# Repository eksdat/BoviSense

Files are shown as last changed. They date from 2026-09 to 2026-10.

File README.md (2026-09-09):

# BoviSense

Sistema embarcado de monitoramento ambiental e controle adaptativo de ventilação para instalações de bovinos leiteiros.

> Projeto acadêmico e experimental desenvolvido com ESP32, sensores ambientais e controle automático de ventilação, com foco em ambiência animal, eficiência energética e possibilidade de futura aplicação em instalações pecuárias reais.

---

## Sobre o projeto

A qualidade ambiental em instalações destinadas a bovinos leiteiros depende de diferentes fatores, incluindo temperatura, umidade relativa, ventilação, concentração de gases e características construtivas do galpão.

Sistemas de ventilação mecânica são utilizados para melhorar as condições ambientais, porém o funcionamento contínuo dos ventiladores pode resultar em consumo energético desnecessário em períodos nos quais a capacidade máxima de ventilação não é necessária.

Este projeto propõe o desenvolvimento de um sistema embarcado capaz de monitorar variáveis ambientais e controlar automaticamente a ventilação de acordo com as condições observadas.

A primeira versão será desenvolvida como uma prova de conceito em escala reduzida.

---

## Problema de pesquisa

A ventilação contínua pode proporcionar condições ambientais adequadas, porém pode consumir energia mesmo quando sua capacidade máxima não é necessária.

Por outro lado, reduzir a ventilação sem considerar as condições ambientais pode prejudicar o conforto térmico dos animais e a qualidade do ar.

A pergunta central do projeto é:

> Um sistema embarcado de controle adaptativo baseado em medições ambientais locais pode reduzir o tempo de operação e o consumo energético da ventilação sem aumentar significativamente o período em condições ambientais inadequadas?

---

## Objetivo geral

Desenvolver e avaliar um sistema embarcado de baixo custo para monitoramento ambiental e controle adaptativo da ventilação em instalações destinadas a bovinos leiteiros.

---

## Objetivos específicos

- monitorar temperatura do ambiente;
- monitorar a resposta de sensores relacionados à qualidade do ar;
- desenvolver um controlador baseado em ESP32;
- implementar diferentes níveis de ventilação;
- desenvolver sinalização local por display;
- registrar dados ambientais e operacionais;
- implementar estados de segurança em caso de falha;
- comparar diferentes estratégias de ventilação;
- avaliar consumo energético e tempo de operação;
- desenvolver uma arquitetura que possa futuramente ser escalada para instalações reais.

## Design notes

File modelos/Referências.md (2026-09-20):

## Modelos e arquivos utilizados

MAKERWORLD. *MQ-2 Sensor Case*. Disponível em: https://makerworld.com/pt/models/1082453-mq-2-sensor-case. Acesso em: 14 set. 2026.

MAKERWORLD. *DHT-11 Sensor Modular Case*. Disponível em: https://makerworld.com/pt/models/1656946-dht-11-sensor-modular-case. Acesso em: 14 set. 2026.

AUTORES. *Case para ESP32 e OLED*. Arquivo 3MF desenvolvido pelos autores. 2026.

AUTORES. *Esquemático estrutural do galpão*. Arquivo 3MF desenvolvido pelos autores. 2026.

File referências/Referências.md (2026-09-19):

# Referências

VITALIANO, Serena; D’URSO, Provvidenza Rita; ARCIDIACONO, Claudia; CASCONE, Giovanni. Ammonia emissions and building-related mitigation strategies in dairy barns: a review. *Agriculture*, v. 14, n. 7, p. 1148, 2024. DOI: https://doi.org/10.3390/agriculture14071148.

CRUZ, Túllio A. M.; NATE, Andressa S. ARIMA modeling for predicting hair coat temperature in dairy cows under heat stress. *Revista Brasileira de Engenharia Agrícola e Ambiental*, v. 30, n. 7, e294454, 2026. DOI: https://doi.org/10.1590/1807-1929/agriambi.v30n7e294454.

BRETTAS, Patrícia K. M.; GUIMARÃES, Ednaldo C.; NASCIMENTO, Mara R. B. M. Dados de estação meteorológica oficial subestimam o estresse por calor em bovinos leiteiros criados em ambiente tropical. *Arquivo Brasileiro de Medicina Veterinária e Zootecnia*, v. 71, n. 3, p. 967-976, 2019. DOI: https://doi.org/10.1590/1678-4162-10432.

AZEVEDO, Marcílio de; PIRES, Maria de Fátima Ávila; SATURNINO, Helton Mattana; LANA, Ângela Maria Quintão; SAMPAIO, Ivan Barbosa Machado; MONTEIRO, João Bosco Neves; MORATO, Leandro Esteves. Estimativa de níveis críticos superiores do índice de temperatura e umidade para vacas leiteiras 1/2, 3/4 e 7/8 Holandês-Zebu em lactação. *Revista Brasileira de Zootecnia*, v. 34, n. 6, p. 2000-2008, 2005. DOI: https://doi.org/10.1590/S1516-35982005000600025.

MYLOSTYVYI, Roman. Heat stress in dairy cattle production: a view from the perspective of sustainable development. *Sustainability*, v. 18, n. 16, p. 8210, 2026. DOI: https://doi.org/10.3390/su18168210.

PARKER, Audrey C.; SAWYER, William J.; RIEDINGER, Kristen A.; BUGHER, Nicolette A.; HART, A. John; PLATA, Desiree L. Dairy barn methane levels and feasibility of thermal catalytic oxidation for net climate benefit. *Environmental Science & Technology*, v. 59, n. 49, p. 26428-26439, 2025. DOI: https://doi.org/10.1021/acs.est.5c06595.

BRETTAS, Patrícia K. de M.; NASCIMENTO, Fernanda G. de O.; BUENO, João P. R.; GUIMARÃES, Ednaldo C.; NASCIMENTO, Mara R. B. de M. Use of the milk composition stress-comfort ratio to monitor heat stress in cows in tropical regions. *Revista Brasileira de Engenharia Agrícola e Ambiental*, v. 29, n. 8, e289847, 2025. DOI: https://doi.org/10.1590/1807-1929/agriambi.v29n8e289847.

SHIN, Jinho; ROH, Heecheol; KIM, Daehun; WI, Jisoo; LEE, Seunghun; AHN, Heekwon. Seasonal and diurnal ammonia emissions from swine-finishing barn with ground channel ventilation. *Animals*, v. 15, n. 13, p. 1892, 2025. DOI: https://doi.org/10.3390/ani15131892.

NEVES, Luiz F. M. et al. Impact of heat stress on intake, performance, digestibility, and health of neonatal dairy calves. *Animals*, v. 15, n. 13, p. 1876, 2025. DOI: https://doi.org/10.3390/ani15131876.

OLIVEIRA, Charles Paranhos et al. Heat stress in dairy cows: impacts, identification, and mitigation strategies: a review. *Animals*, v. 15, n. 2, p. 249, 2025. DOI: https://doi.org/10.3390/ani15020249.

EDWARDS, Kristen Y.; RENAUD, David L. A framework for comprehensive dairy calf health investigations. *Animals*, v. 15, n. 2, p. 181, 2025. DOI: https://doi.org/10.3390/ani15020181.

RAKIB, M. R. H. et al. Graduate student literature review: potential use of HSP70 as an indicator of heat stress in dairy cows: a review. *Journal of Dairy Science*, v. 107, n. 12, p. 11597-11610, 2024. DOI: https://doi.org/10.3168/jds.2024-24947.

FERNANDES, Carlos Otávio Mader; VALOIS, Cassio Marques de; PILGER, Jean Pierre. *Instalações para gado de leite*. Boletim Técnico, n. 208. Florianópolis: Epagri, 2024. Disponível em: https://publicacoes.epagri.sc.gov.br/BT/article/view/1913. Acesso em: 19 set. 2026.

CASTRO, A. L. O. et al. Parâmetros fisiológicos de vacas F1 Holandês x Zebu criadas em ambientes com e sem sombreamento. *Arquivo Brasileiro de Medicina Veterinária e Zootecnia*, v. 70, n. 3, p. 722-730, 2018. DOI: https://doi.org/10.1590/1678-4162-9305.

ARCARO JÚNIOR, Irineu et al. Respostas fisiológicas de vacas em lactação à ventilação e aspersão na sala de espera. *Ciência Rural*, v. 35, n. 3, p. 639-643, 2005. DOI: https://doi.org/10.1590/S0103-84782005000300024.

NASCIMENTO, Fernanda Gatti de Oliveira et al. What is the best temperature-humidity index equation to indicate heat stress in crossbred dairy calves in a tropical environment? *Ciência Rural*, v. 49, n. 1, e20180132, 2019. DOI: https://doi.org/10.1590/0103-8478cr20180132.

COSTA, Cláudio Nápolis; FREITAS, Marcelo Silva de; FREITAS, Ary Ferreira de; VIANELLO, Rubens Leite; BARRA, Ricardo Bertola. Efeito do estresse térmico na produção de leite de animais da raça Holandesa em Minas Gerais. In: REUNIÃO ANUAL DA SOCIEDADE BRASILEIRA DE ZOOTECNIA, 44., 2007, Jaboticabal. *O avanço científico e tecnológico na produção animal: anais*. Viçosa, MG: Sociedade Brasileira de Zootecnia, 2007. Disponível em: https://www.embrapa.br/en/busca-de-publicacoes/-/publicacao/595721/efeito-do-estresse-termico-na-producao-de-leite-de-animais-da-raca-holandesa-em-minas-gerais. Acesso em: 19 set. 2026.

NOSEK, Štěpán et al. Review of wind tunnel modelling of flow and pollutant dispersion within and from naturally ventilated livestock buildings. *Applied Sciences*, v. 11, n. 9, p. 3783, 2021. DOI: https://doi.org/10.3390/app11093783.

HOFFMANN, G. et al. Animal-related, non-invasive indicators for determining heat stress in dairy cows. *Biosystems Engineering*, v. 199, p. 83-96, 2020. DOI: https://doi.org/10.1016/j.biosystemseng.2019.10.017.

RODRIGUES, Ana R. F. et al. Implications of seasonal and daily variation on methane and ammonia emissions from naturally ventilated dairy cattle barns in a Mediterranean climate: a two-year study. *Science of the Total Environment*, v. 946, p. 173734, 2024. DOI: https://doi.org/10.1016/j.scitotenv.2024.173734.

TABASE, Raphael Kubeba; NÆSS, Geir; LARRING, Yngve. Ammonia and methane emissions from small herd cattle buildings in a cold climate. *Science of the Total Environment*, v. 903, p. 166046, 2023. DOI: https://doi.org/10.1016/j.scitotenv.2023.166046.

ÇINAR, Gültac et al. Effects of environmental and housing system factors on ammonia and greenhouse gas emissions from cattle barns: a meta-analysis of a global data collation. *Waste Management*, v. 172, p. 60-70, 2023. DOI: https://doi.org/10.1016/j.wasman.2023.09.007.

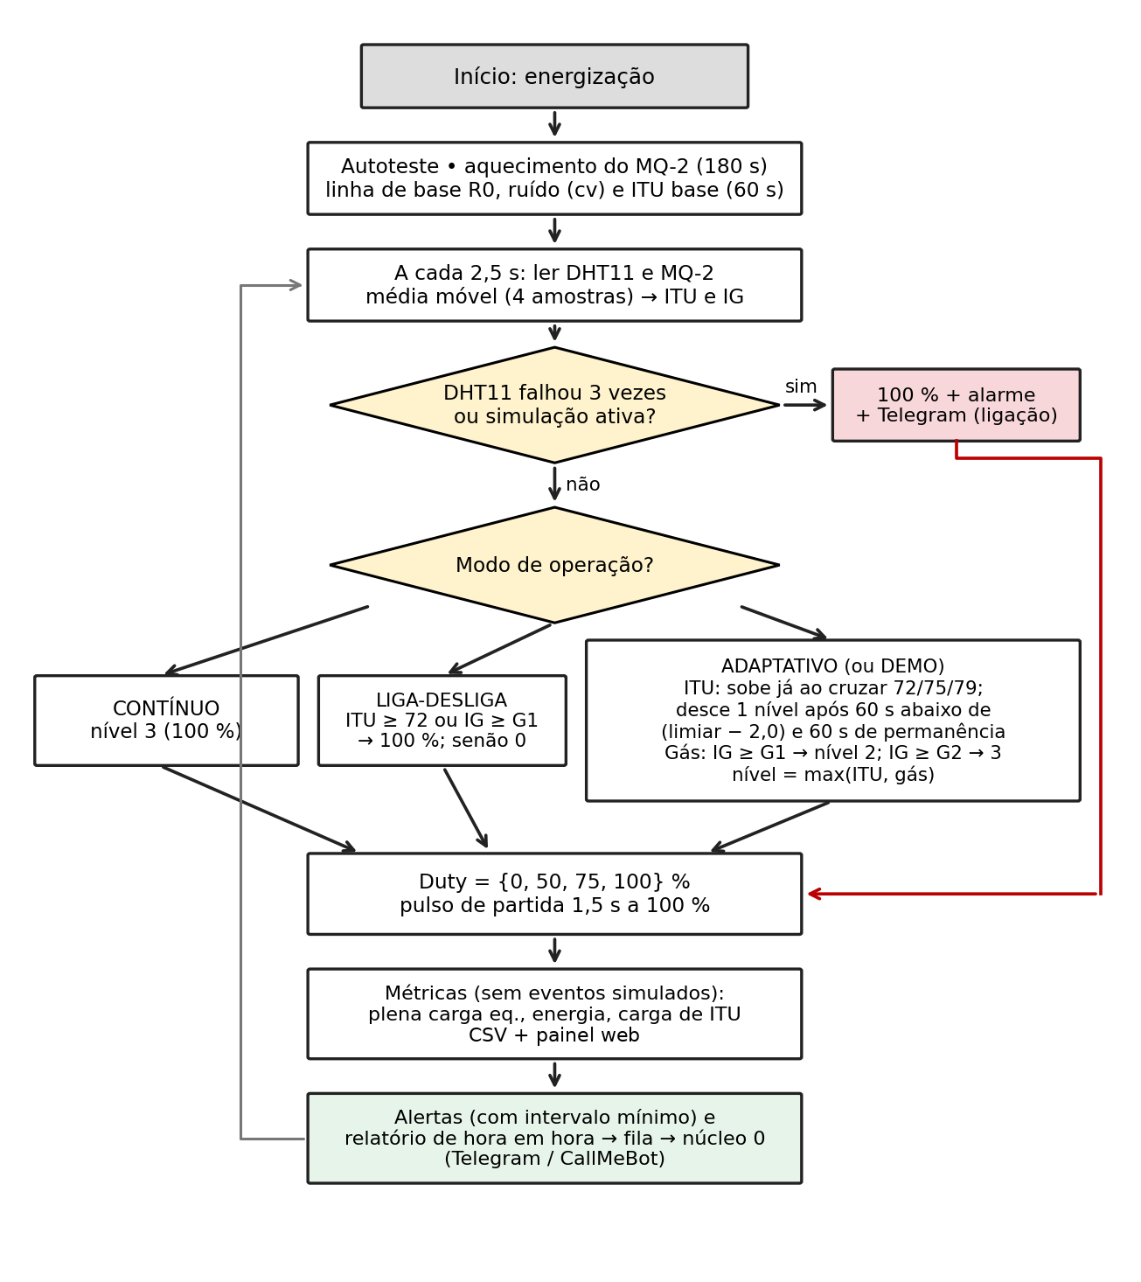
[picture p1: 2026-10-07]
figuras/fig5_fluxograma.png

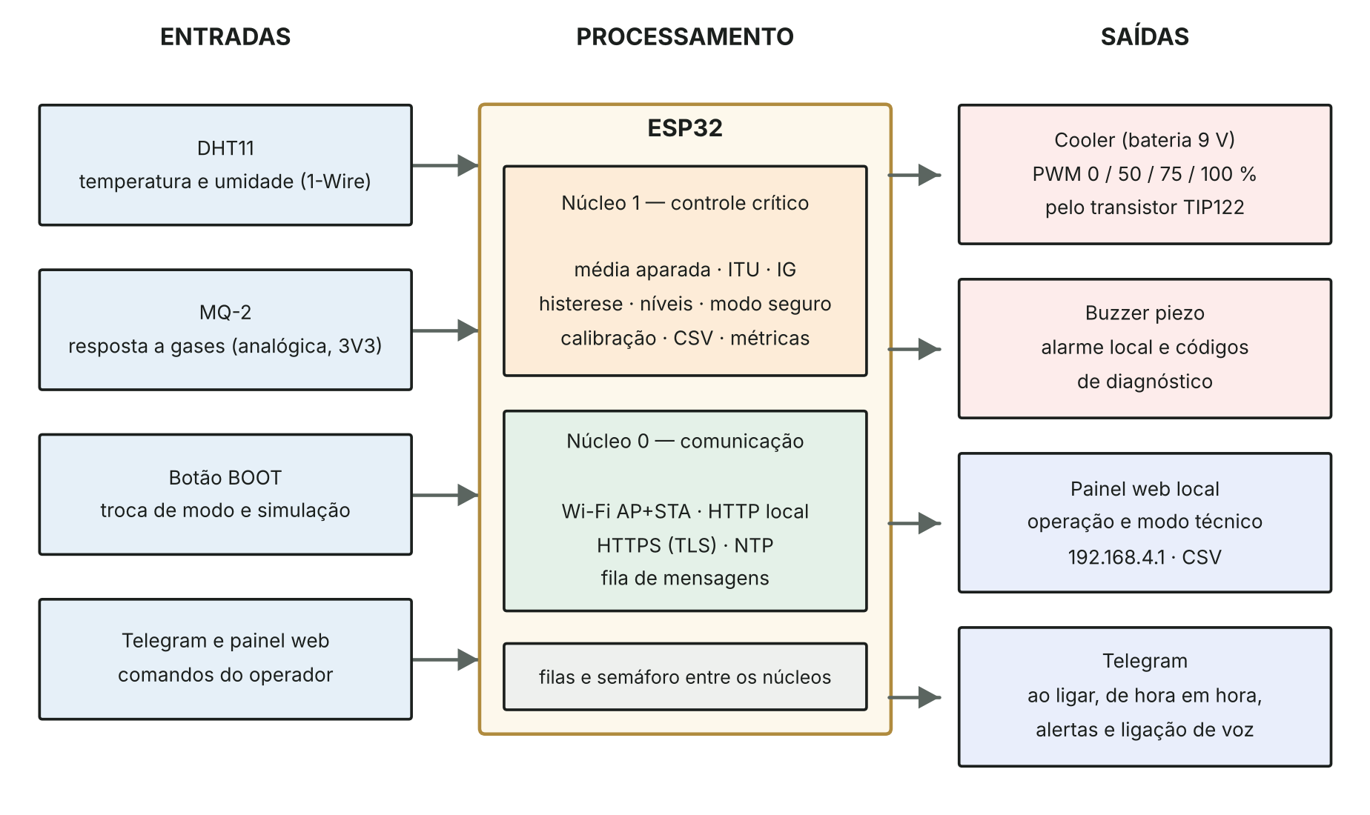
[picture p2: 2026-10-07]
figuras/fig1_diagrama_blocos.png

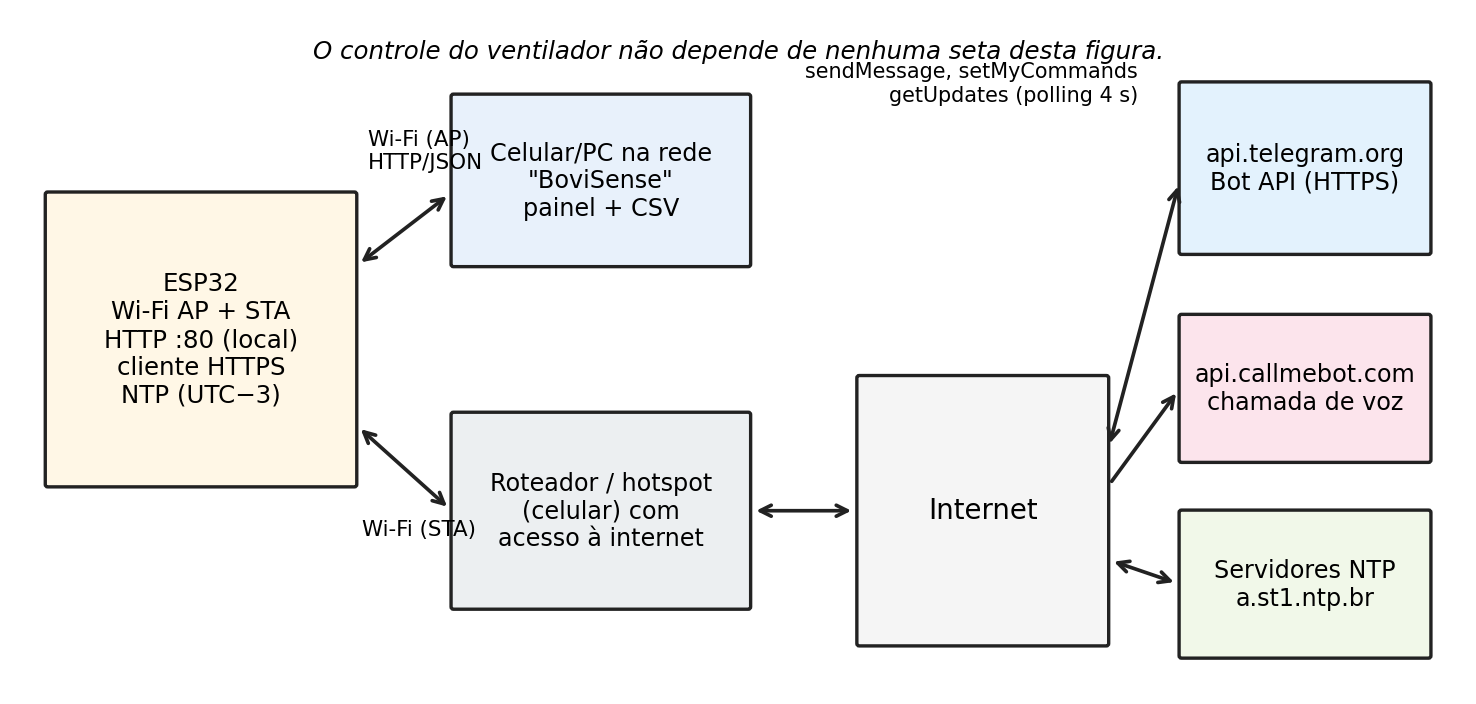
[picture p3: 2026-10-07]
figuras/fig6_arquitetura_rede.png

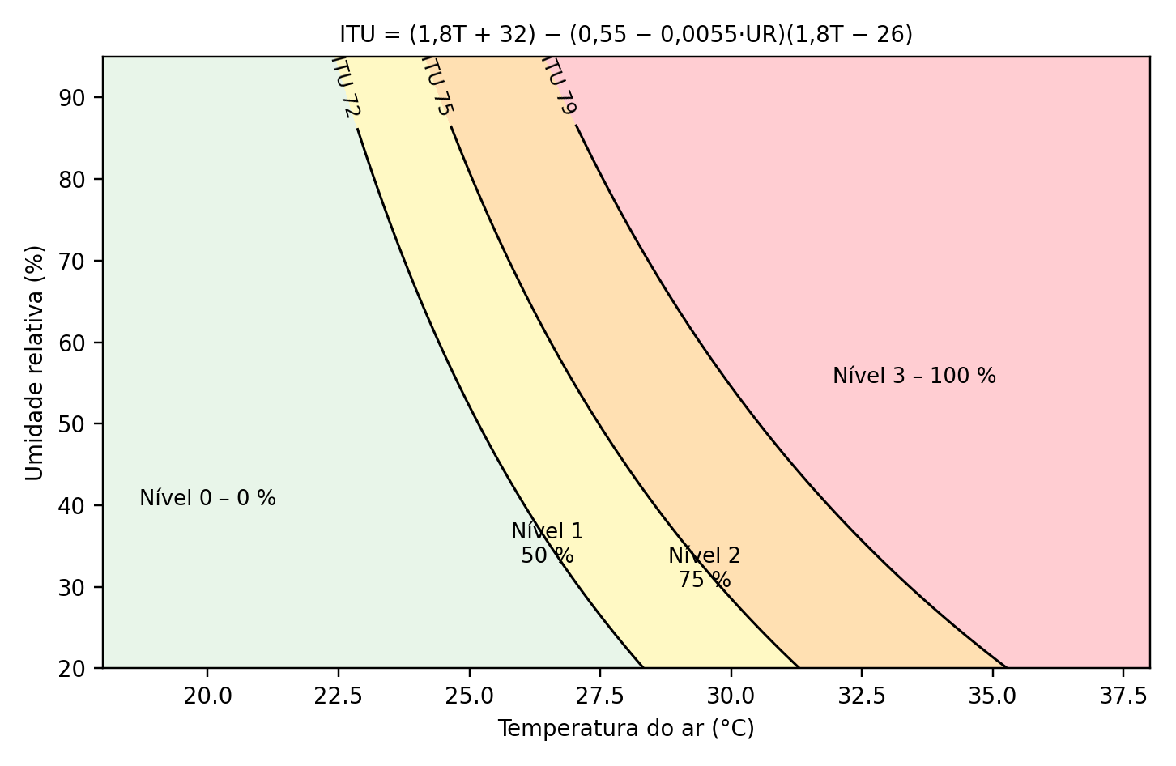
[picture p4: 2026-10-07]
figuras/fig4_mapa_itu.png

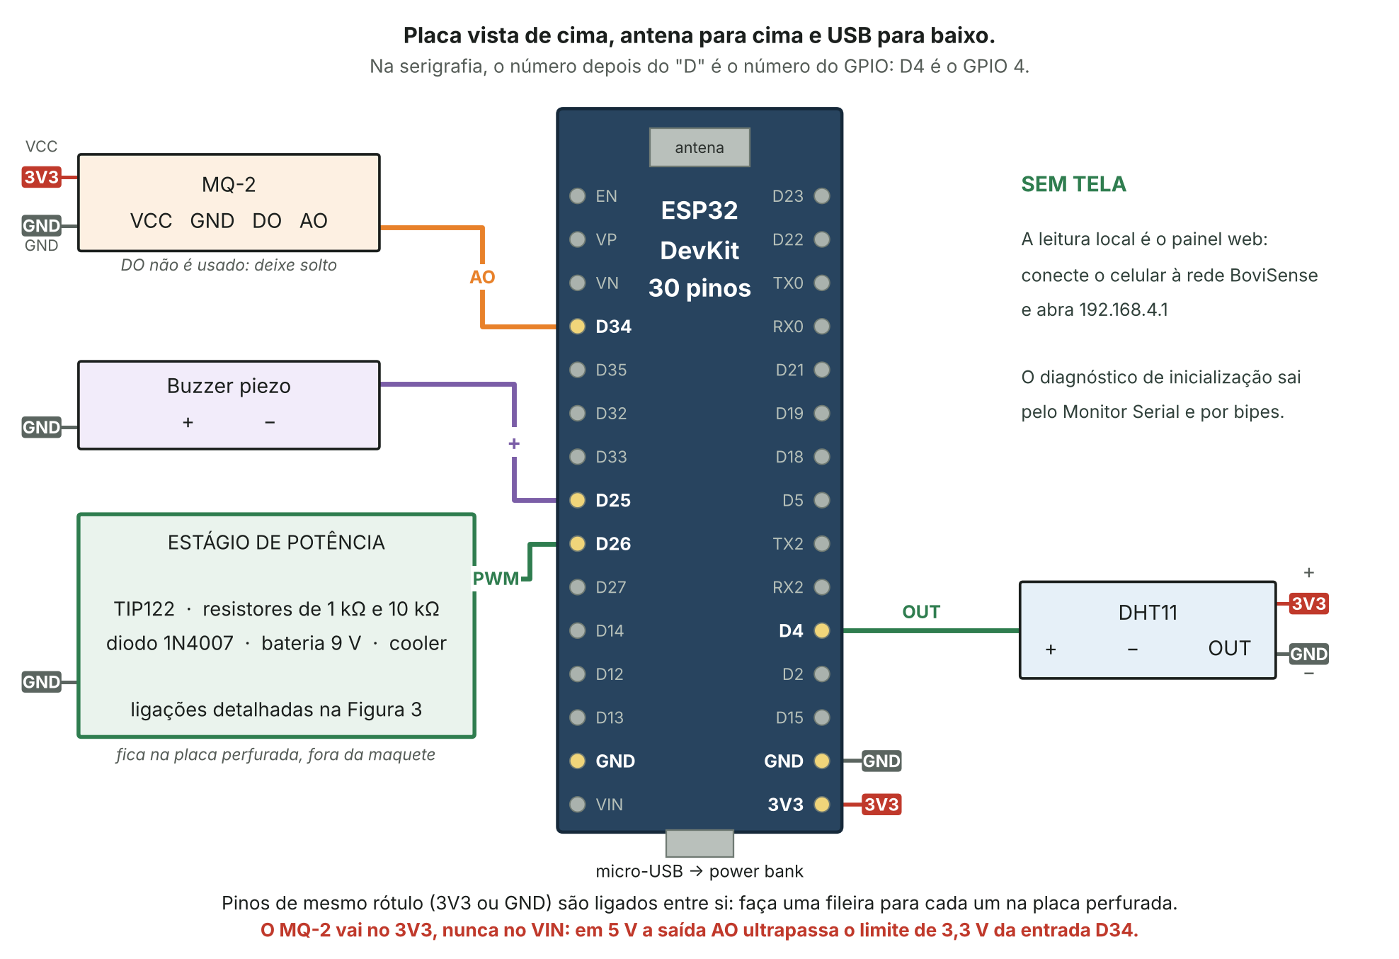
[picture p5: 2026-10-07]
figuras/fig2_esquema_ligacoes.png

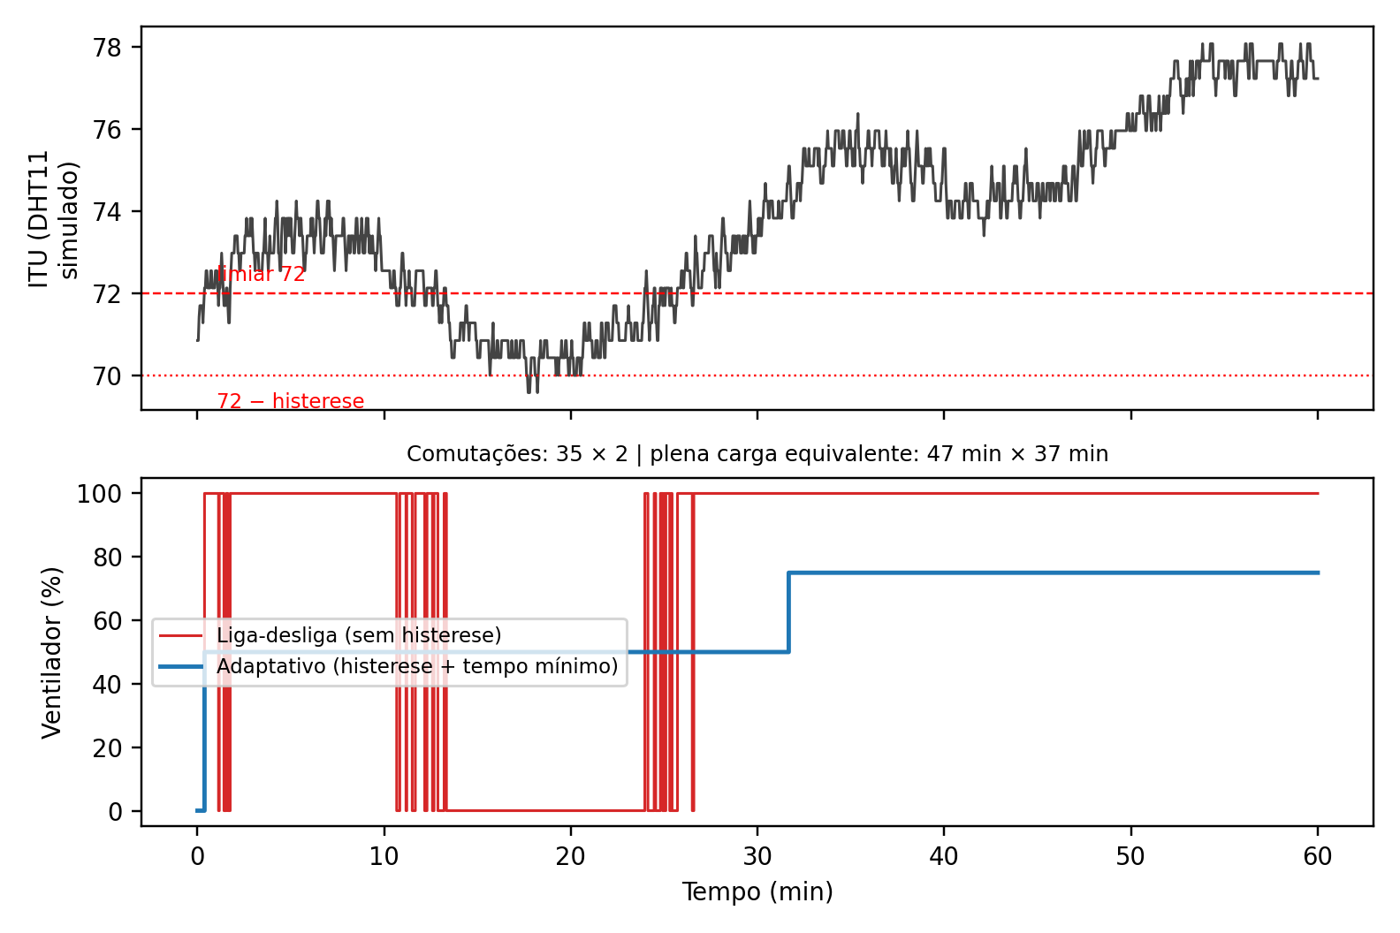
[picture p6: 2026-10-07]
figuras/fig7_simulacao.png

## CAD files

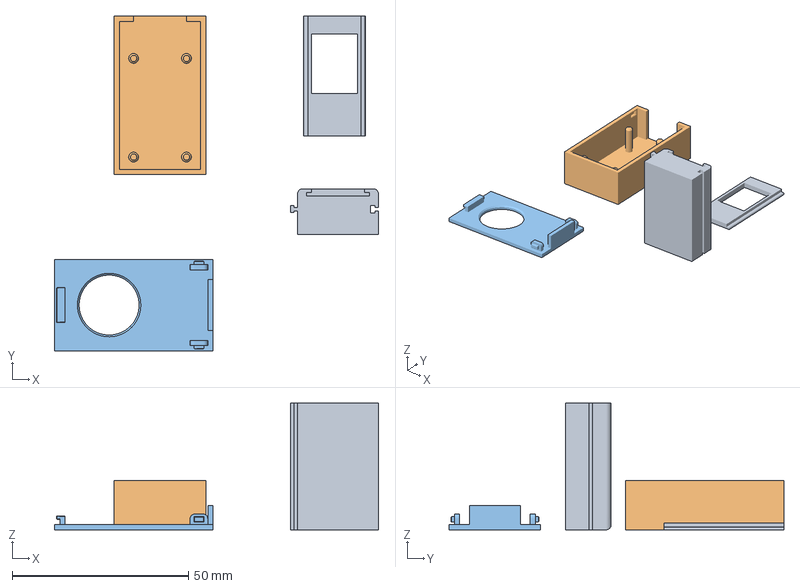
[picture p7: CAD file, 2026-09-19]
modelos/MQ-2.3mf
92.0 x 95.0 x 36.0 mm
DHT11 Sensor Modular Case.stl
MQ-2 sensor case.stl_1
MQ-2 sensor case.stl_2

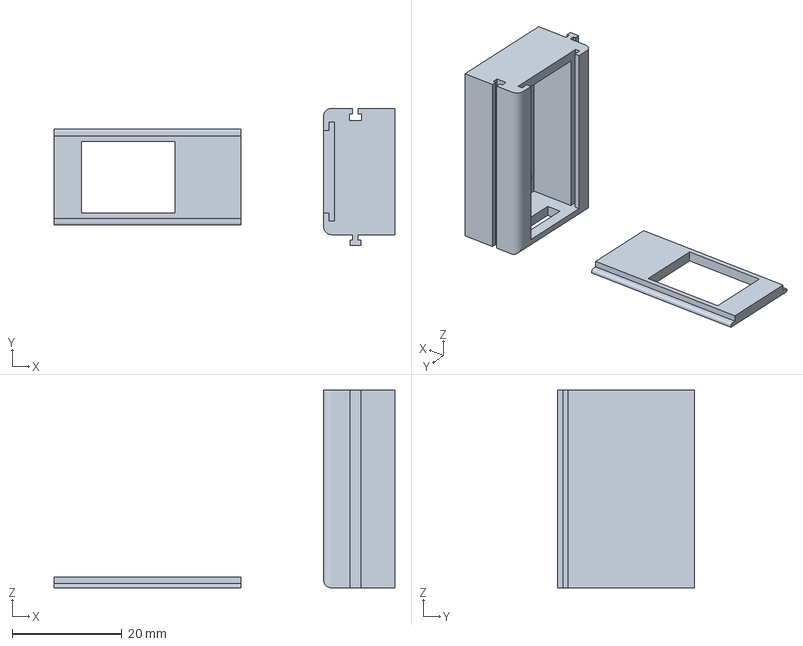
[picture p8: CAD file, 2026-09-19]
modelos/DHT11.3mf
62.0 x 25.0 x 36.0 mm

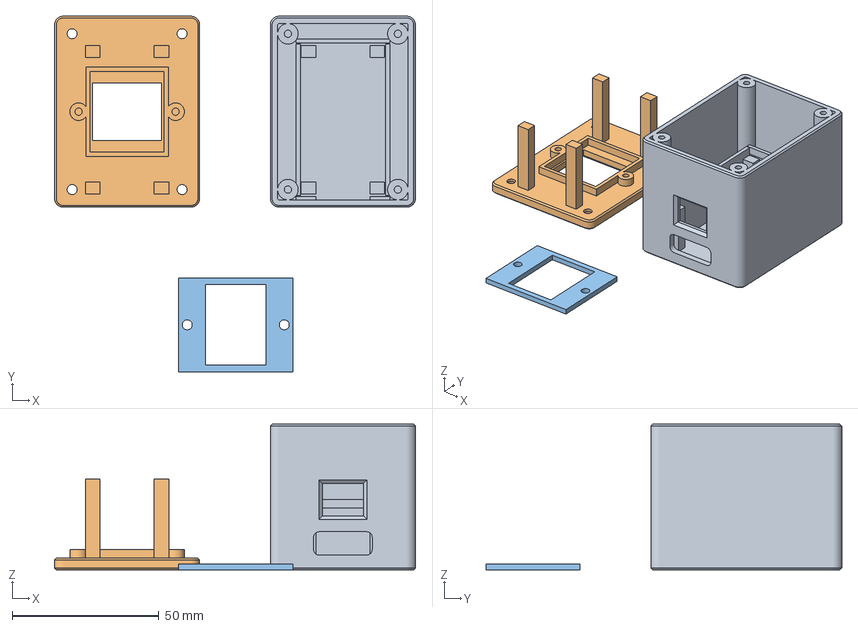
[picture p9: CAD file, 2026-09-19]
modelos/case.3mf
122.8 x 121.0 x 49.6 mm
PRINT_1_CORPO
PRINT_2_TAMPA
PRINT_3_RETENCAO

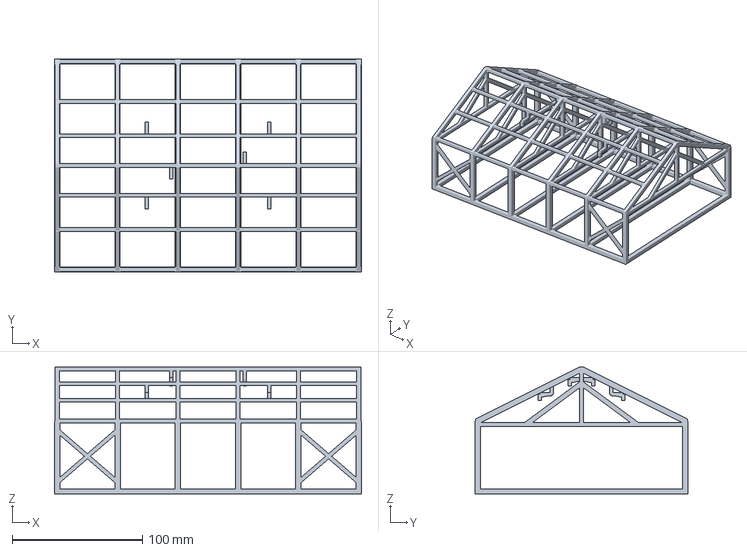
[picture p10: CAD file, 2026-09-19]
modelos/galpao.3mf
236.0 x 164.0 x 97.6 mm

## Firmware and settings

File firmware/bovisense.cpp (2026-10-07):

/*
 * ============================================================================
 *  BoviSense — monitoramento ambiental e ventilação adaptativa para bovinos
 *  ESP32 DevKit 30 pinos | DHT11 | MQ-2 | buzzer | TIP122
 *
 *  - Painel web BoviSense (rede "BoviSense", http://192.168.4.1), com duas
 *    vistas: OPERAÇÃO (só o que o usuário final precisa ver) e TÉCNICO
 *    (perfil de teste: estratégias, ensaios, métricas, calibração e rede)
 *  - Telegram: mensagem ao ligar, relatório de hora em hora, alertas,
 *    comandos pelo menu "/" e simulação de emergência com ligação de voz
 *  - Calibração: offsets do DHT11 contra referência (gravados na memória),
 *    ADC com média aparada, linha de base do MQ-2 com correção lenta de deriva
 *
 *  Sem display: a interface local é o painel web. O diagnóstico de
 *  inicialização sai pelo Monitor Serial e por códigos de bipe no buzzer.
 *
 *  Compatível com Arduino-ESP32 core 2.0.x e 3.x. Bibliotecas:
 *    DHT sensor library, Adafruit Unified Sensor, ArduinoJson (v7).
 *
 *  VALIDADE CIENTÍFICA: o MQ-2 não mede NH3 e nada aqui é convertido em ppm;
 *  IG = R0/Rs é um índice relativo. ITU: Kelly e Bond (1971) apud Azevedo
 *  et al. (2005). Limiares 72/75/79: Armstrong (1994) apud Azevedo et al.
 *  (2005) e valores críticos de Azevedo et al. (2005). Eventos simulados são
 *  marcados no registro e NÃO entram nas métricas dos ensaios.
 * ============================================================================
 */
#include <Arduino.h>
#if __has_include(<esp_arduino_version.h>)
#include <esp_arduino_version.h>
#endif
#include <DHT.h>
#include <WiFi.h>
#include <WebServer.h>
#include <WiFiClientSecure.h>
#include <HTTPClient.h>
#include <ArduinoJson.h>
#include <Preferences.h>
#include <esp_wifi.h>
#include <time.h>
#include "segredos.h"

#if defined(ESP_ARDUINO_VERSION_MAJOR) && (ESP_ARDUINO_VERSION_MAJOR >= 3)
#define CORE3 1
#else
#define CORE3 0
#endif

// ============================ 0. HARDWARE ==================================
#define SEM_ATUADOR   0   // 1 = sem TIP122: só recomenda o nível (modo sombra)
#define MQ2_EM_3V3    1   // 1 = MQ-2 no 3V3, AO direto; 0 = MQ-2 no VIN com divisor 10k/20k

// ============================ 1. PINOS =====================================
// Na placa, o número depois do "D" é o número do GPIO (D4 = GPIO4).
#define PIN_DHT      4    // D4  -> OUT do DHT11
#define PIN_MQ2      34   // D34 -> AO do MQ-2 (entrada analógica ADC1)
#define PIN_FAN      26   // D26 -> resistor 1 kΩ -> base do TIP122
#define PIN_BUZZER   25   // D25 -> + do buzzer
#define PIN_BOTAO    0    // botão BOOT da placa
#define PIN_LED      2    // LED azul da placa

// ============================ 2. SENSORES ==================================
#define DHT_TIPO        DHT11
#define OFFSET_T_C      0.0f   // offsets fixos (além da calibração salva pelo painel)
#define OFFSET_UR_PCT   0.0f
#if MQ2_EM_3V3
#define MQ2_R1_OHM 0.0f
#define MQ2_R2_OHM 1.0f
#define MQ2_VC_MV  3300.0f
#else
#define MQ2_R1_OHM 10000.0f
#define MQ2_R2_OHM 20000.0f
#define MQ2_VC_MV  5000.0f
#endif
#define ADC_N           32       // leituras por amostra (média aparada)
#define SALTO_T_MAX     3.0f     // rejeição de pico do DHT11 (°C entre amostras)
#define SALTO_U_MAX     10.0f    // (% UR entre amostras)
#define TAU_DERIVA_S    1800.0f  // correção lenta da linha de base do MQ-2

// ============================ 3. TEMPOS ====================================
#define T_AMOSTRA_MS       2500UL
#define N_MEDIA            4
#define T_AQUEC_S          180UL
#define T_BASE_S           60UL
#define T_DESCIDA_MS       60000UL
#define T_PERMANENCIA_MS   60000UL
#define T_PARTIDA_MS       1500UL
#define FALHAS_FAILSAFE    3
#define T_SIM_MS           60000UL   // duração da emergência simulada
#define T_BOTAO_SIM_MS     3000UL    // segurar BOOT 3 s = simular emergência

// ============================ 4. CONTROLE ==================================
static float ITU_LIMIAR[3] = {72.0f, 75.0f, 79.0f};
#define ITU_HISTERESE   2.0f     // DHT11 (1 °C de resolução ≈ 1,4 ITU); DHT22: 1.0f
static const uint8_t DUTY_NIVEL[4] = {0, 50, 75, 100};
static float IG_LIMIAR[2] = {1.5f, 2.5f};
#define IG_HISTERESE    0.2f
#define FAN_PWM_HZ      1000
#define FAN_PWM_BITS    10
#define FAN_INVERTIDO   0
#define FAN_P_NOMINAL_W 2.4f     // substituir pela potência medida (Ensaio 0)
static float P_NIVEL_W[4] = {0.0f, 0.50f * FAN_P_NOMINAL_W, 0.75f * FAN_P_NOMINAL_W, FAN_P_NOMINAL_W};

// ============================ 5. ALERTAS ===================================
#define ALERTA_ITU_S     120
#define LIGACAO_ITU_S    600
#define COOLDOWN_MSG_S   600
#define COOLDOWN_LIG_S   1800
#define LEMBRETE_BIP_S   30
#define TG_POLL_MS       4000
#define INTERVALO_LIG_SIM_MS 120000UL  // no máximo 1 ligação simulada a cada 2 min

// ============================ TIPOS ========================================
enum Modo : uint8_t { MODO_CONTINUO = 0, MODO_LIGA_DESLIGA, MODO_ADAPTATIVO, MODO_DEMO };
static const char *NOME_MODO[] = {"CONTINUO", "LIGA-DESLIGA", "ADAPTATIVO", "DEMO"};
enum Estado : uint8_t { EST_AQUEC = 0, EST_BASE, EST_OPER };

struct Estagiador { const float *limiar; uint8_t n; float hist; uint8_t estagio; uint32_t ultimaTroca; bool abaixo; uint32_t abaixoDesde; };
struct Metricas {
  uint32_t inicio_ms;
  double t_total_s, t_ligado_s, t_eq_s, t_itu_acima_s, carga_itu_min, energia_wh, t_nivel_s[4], soma_itu;
  uint32_t n_partidas, n_trocas, n_itu;
  float itu_max, itu_min, ig_max;
};
struct Registro { uint32_t t; int16_t T10, U10, ITU10; uint16_t IG100, mv; uint8_t nivel, duty, modo; uint16_t flags; };
#define N_REG 1500
static Registro regs[N_REG];
static uint16_t regTopo = 0, regQtd = 0;

#define F_DHT_FALHA   0x001
#define F_FAILSAFE    0x002
#define F_MQ_FALHA    0x004
#define F_PREPARO     0x008
#define F_ALARME_GAS  0x010
#define F_PARTIDA     0x020
#define F_UR_FAIXA    0x040
#define F_HORA_NTP    0x080
#define F_SIMULACAO   0x100
#define F_RECAL_GAS   0x200

struct Retrato { float T, U, itu, ig; uint8_t nivel, duty, modo, estado; uint16_t flags; bool sim; Metricas ensaio, hora, ensS[3], horS[3]; };
enum TipoSaida : uint8_t { SAI_MSG = 0, SAI_LIGACAO };
struct MsgSaida { uint8_t tipo; char texto[900]; };
enum TipoCmd : uint8_t { CMD_MODO = 0, CMD_NOVO_ENSAIO, CMD_SIMULAR, CMD_PARAR_SIM, CMD_RECAL_GAS };
struct Comando { uint8_t tipo; int arg; };

// ============================ OBJETOS GLOBAIS ==============================
DHT dht(PIN_DHT, DHT_TIPO);
WebServer servidor(80);
Preferences prefs;
SemaphoreHandle_t mtx;
QueueHandle_t filaSaida, filaCmd;

static String wifiSsid, wifiSenha, tgToken, tgChat, cbUser;   // gravadas na memória e editáveis pelo painel
static volatile bool pedidoReconectar = false;
static bool wifiOk = false;
static volatile uint8_t wifiMotivo = 0;   // último motivo de desconexão informado pelo driver
static char wifiDiag[40] = "-";
static Modo modo = MODO_ADAPTATIVO;
static Estado estado = EST_AQUEC;
static uint32_t tInicioEstado = 0, ultimaAmostra = 0;

static float bufT[N_MEDIA], bufU[N_MEDIA], bufR[N_MEDIA];
static uint8_t idxTU = 0, nTU = 0, idxR = 0, nR = 0, rejeicoes = 0;
static uint8_t falhasDHT = 0;
static float Traw = NAN, Uraw = NAN, Tf = NAN, Uf = NAN, itu = NAN, ig = NAN, tLongo = NAN, uLongo = NAN;
static uint32_t mqmV = 0;
static float R0rel = NAN, cvBase = 0, ituBase = NAN, calOffT = 0, calOffU = 0;
static double somaR = 0, somaR2 = 0, somaItuBase = 0; static uint32_t nBaseR = 0, nBaseItu = 0;
static uint32_t recalGasAte = 0;
static float ituDemo[3] = {0, 0, 0};

static Estagiador stItu = {ITU_LIMIAR, 3, ITU_HISTERESE, 0, 0, false, 0};
static Estagiador stGas = {IG_LIMIAR, 2, IG_HISTERESE, 0, 0, false, 0};

static uint8_t nivel = 0, dutyAlvo = 0, dutyAnterior = 0;
static uint16_t flags = 0;
static uint32_t partidaAte = 0;
static Metricas ensaio, hora, ensS[3], horS[3];
static uint8_t dutyPrevS[3] = {0, 0, 0};
static Retrato retrato;

static uint32_t ituCritDesde = 0; static bool ituCritAtivo = false, ituAvisou = false;
static bool gasAlarme = false, failsafeAtivo = false;
static uint32_t ultMsg[3] = {0, 0, 0}, ultLig[3] = {0, 0, 0};
static uint32_t ultLembrete = 0;
static int ultimaHoraRelatorio = -1; static uint32_t ultRelatorioMs = 0;
static uint32_t simAte = 0, ultLigSim = 0; static bool simAnterior = false;
static uint32_t bipFim = 0, bipProx = 0; static uint8_t bipsPend = 0;

// ============================ PWM (LEDC) ===================================
#define CANAL_FAN 0
#define CANAL_BUZ 2
static void pwmIniciar() {
#if CORE3
  ledcAttachChannel(PIN_FAN, FAN_PWM_HZ, FAN_PWM_BITS, CANAL_FAN);
  ledcAttachChannel(PIN_BUZZER, 2000, 10, CANAL_BUZ);
  ledcWrite(PIN_BUZZER, 0);
#else
  ledcSetup(CANAL_FAN, FAN_PWM_HZ, FAN_PWM_BITS); ledcAttachPin(PIN_FAN, CANAL_FAN);
  ledcSetup(CANAL_BUZ, 2000, 10); ledcAttachPin(PIN_BUZZER, CANAL_BUZ);
  ledcWrite(CANAL_BUZ, 0);
#endif
}
static void fanEscrever(uint8_t pct) {
  if (SEM_ATUADOR) pct = 0;
  uint32_t maxv = (1UL << FAN_PWM_BITS) - 1, d = (uint32_t)pct * maxv / 100UL;
  if (FAN_INVERTIDO) d = maxv - d;
#if CORE3
  ledcWrite(PIN_FAN, d);
#else
  ledcWrite(CANAL_FAN, d);
#endif
}
static void buzzerTom(uint32_t f) {
#if CORE3
  if (f == 0) ledcWrite(PIN_BUZZER, 0); else ledcWriteTone(PIN_BUZZER, f);
#else
  if (f == 0) ledcWrite(CANAL_BUZ, 0); else ledcWriteTone(CANAL_BUZ, f);
#endif
}
static void bipsAgendar(uint8_t n) { if (n > bipsPend) bipsPend = n; bipProx = millis(); }
static void bipServico() {
  uint32_t agora = millis();
  if (bipFim && (int32_t)(agora - bipFim) >= 0) { buzzerTom(0); bipFim = 0; }
  if (!bipFim && bipsPend && (int32_t)(agora - bipProx) >= 0) { buzzerTom(2200); bipFim = agora + 150; bipsPend--; bipProx = agora + 350; }
}

// ============================ CÁLCULOS =====================================
static float calcITU(float T, float UR) { return (1.8f * T + 32.0f) - (0.55f - 0.0055f * UR) * (1.8f * T - 26.0f); }
static float media(const float *b, uint8_t n) { float s = 0; for (uint8_t i = 0; i < n; i++) s += b[i]; return n ? s / n : NAN; }
// Média aparada: ordena ADC_N leituras e usa a metade central (remove picos do Wi-Fi)
static uint32_t lerMQ2mV() {
  uint16_t v[ADC_N];
  for (int i = 0; i < ADC_N; i++) { v[i] = analogReadMilliVolts(PIN_MQ2); delayMicroseconds(200); }
  for (int i = 1; i < ADC_N; i++) { uint16_t x = v[i]; int j = i - 1; while (j >= 0 && v[j] > x) { v[j + 1] = v[j]; j--; } v[j + 1] = x; }
  uint32_t s = 0; for (int i = ADC_N / 4; i < 3 * ADC_N / 4; i++) s += v[i];
  return s / (ADC_N / 2);
}
static bool horaValida() { return time(nullptr) > 1700000000; }
static uint32_t carimbo() { return horaValida() ? (uint32_t)time(nullptr) : millis() / 1000UL; }
static bool simulando() { return simAte && (int32_t)(simAte - millis()) > 0; }
static const float *limiaresAtivos() { return (modo == MODO_DEMO) ? ituDemo : ITU_LIMIAR; }
static uint8_t categoria(float x) {
  if (isnan(x)) return 255;
  const float *l = limiaresAtivos(); uint8_t c = 0;
  for (int k = 0; k < 3; k++) if (x >= l[k]) c = k + 1;
  return c;
}
static const char *NOME_CAT[4] = {"Conforto termico", "Estresse brando", "Atencao: quase critico", "Estresse moderado"};

static uint8_t estagiar(Estagiador &e, float x, uint32_t agora) {
  uint8_t alvo = 0;
  for (uint8_t k = 0; k < e.n; k++) if (x >= e.limiar[k]) alvo = k + 1;
  if (alvo > e.estagio) { e.estagio = alvo; e.ultimaTroca = agora; e.abaixo = false; return e.estagio; }
  if (e.estagio > 0 && x < e.limiar[e.estagio - 1] - e.hist) {
    if (!e.abaixo) { e.abaixo = true; e.abaixoDesde = agora; }
    if (agora - e.abaixoDesde >= T_DESCIDA_MS && agora - e.ultimaTroca >= T_PERMANENCIA_MS) { e.estagio--; e.ultimaTroca = agora; e.abaixo = false; }
  } else e.abaixo = false;
  return e.estagio;
}
static void zerarEstagiador(Estagiador &e) { e.estagio = 0; e.ultimaTroca = millis(); e.abaixo = false; }
static void zerarMetricas(Metricas &m) { memset(&m, 0, sizeof(m)); m.inicio_ms = millis(); m.itu_max = -1000; m.itu_min = 1000; }
static void zerarEnsaio() { zerarMetricas(ensaio); for (int i = 0; i < 3; i++) { zerarMetricas(ensS[i]); dutyPrevS[i] = 0; } }
static void zerarHora() { zerarMetricas(hora); for (int i = 0; i < 3; i++) zerarMetricas(horS[i]); }
static void acumular(Metricas &m, float dt, uint8_t niv, uint8_t duty, bool partida, bool troca) {
  m.t_total_s += dt; m.t_nivel_s[niv] += dt;
  if (duty > 0) m.t_ligado_s += dt;
  m.t_eq_s += dt * duty / 100.0;
  m.energia_wh += P_NIVEL_W[niv] * dt / 3600.0;
  if (partida) m.n_partidas++;
  if (troca) m.n_trocas++;
  if (!isnan(itu)) {
    m.n_itu++; m.soma_itu += itu;
    if (itu > m.itu_max) m.itu_max = itu;
    if (itu < m.itu_min) m.itu_min = itu;
    if (itu >= ITU_LIMIAR[0]) { m.t_itu_acima_s += dt; m.carga_itu_min += (itu - ITU_LIMIAR[0]) * dt / 60.0; }
  }
  if (!isnan(ig) && ig > m.ig_max) m.ig_max = ig;
}

// ============================ CALIBRAÇÃO (memória permanente) ==============
static void carregarCalibracao() {
  prefs.begin("bovisense", true);
  calOffT = prefs.getFloat("offT", 0.0f); calOffU = prefs.getFloat("offU", 0.0f);
  wifiSsid = prefs.getString("wifi_s", WIFI_SSID); wifiSenha = prefs.getString("wifi_p", WIFI_SENHA);
  tgToken = prefs.getString("tg_t", TG_TOKEN); tgChat = prefs.getString("tg_c", TG_CHAT_ID);
  cbUser = prefs.getString("cb_u", CALLMEBOT_USER);
  prefs.end();
}
// A rede escolhida no painel fica gravada; o segredos.h serve só de valor inicial
static void salvarRede(const String &ssid, const String &senha) {
  wifiSsid = ssid; wifiSenha = senha;
  prefs.begin("bovisense", false); prefs.putString("wifi_s", ssid); prefs.putString("wifi_p", senha); prefs.end();
  pedidoReconectar = true;
}
static void salvarTelegram(const String &tok, const String &chat, const String &user) {
  tgToken = tok; tgChat = chat; cbUser = user;
  prefs.begin("bovisense", false); prefs.putString("tg_t", tok); prefs.putString("tg_c", chat); prefs.putString("cb_u", user); prefs.end();
}
static void salvarCalibracao() {
  prefs.begin("bovisense", false);
  prefs.putFloat("offT", calOffT); prefs.putFloat("offU", calOffU);
  prefs.end();
}
// Ajusta os offsets para que a média de 60 s do DHT11 coincida com a referência
static bool calibrarTU(float tRef, float uRef, char *msg, size_t n) {
  if (isnan(tLongo) || isnan(uLongo)) { snprintf(msg, n, "Sem leituras suficientes do DHT11."); return false; }
  if (tRef < 0 || tRef > 50 || uRef < 5 || uRef > 100) { snprintf(msg, n, "Referencia fora da faixa (T 0-50 C, UR 5-100 %%)."); return false; }
  float dT = tRef - tLongo, dU = uRef - uLongo;
  if (fabsf(calOffT + dT) > 10 || fabsf(calOffU + dU) > 25) { snprintf(msg, n, "Correcao grande demais: confira o sensor e a referencia."); return false; }
  calOffT += dT; calOffU += dU;
  for (int i = 0; i < N_MEDIA; i++) { bufT[i] += dT; bufU[i] += dU; }
  tLongo += dT; uLongo += dU; salvarCalibracao();
  snprintf(msg, n, "Calibrado: offset T %+.1f C, UR %+.1f %% (salvo na memoria).", calOffT, calOffU);
  return true;
}
static void zerarCalibracao() {
  for (int i = 0; i < N_MEDIA; i++) { bufT[i] -= calOffT; bufU[i] -= calOffU; }
  if (!isnan(tLongo)) { tLongo -= calOffT; uLongo -= calOffU; }
  calOffT = calOffU = 0; salvarCalibracao();
}
static void iniciarRecalGas() { recalGasAte = millis() + T_BASE_S * 1000UL; somaR = somaR2 = 0; nBaseR = 0; zerarEstagiador(stGas); }
static void definirLimiaresGas() {
  if (nBaseR < 5) return;
  R0rel = somaR / nBaseR;
  double var = somaR2 / nBaseR - (double)R0rel * R0rel;
  cvBase = var > 0 ? sqrt(var) / R0rel : 0;
  IG_LIMIAR[0] = max(1.5f, 1.0f + 6.0f * cvBase);
  IG_LIMIAR[1] = max(2.5f, IG_LIMIAR[0] + 0.5f);
}

// ============================ SAÍDAS DE REDE ===============================
static bool chatIdValido() {
  const char *id = tgChat.c_str(); if (!*id) return false;
  for (const char *p = id; *p; p++) if (!(isdigit((unsigned char)*p) || (*p == '-' && p == id))) return false;
  return true;
}
static bool tgTokenOk() { return tgToken.length() > 20; }
static bool tgAtivo() { return tgTokenOk() && chatIdValido(); }
static bool ligacaoAtiva() { return cbUser.length() > 1; }
static void enfileirar(uint8_t tipo, const char *txt) {
  if (tipo == SAI_MSG && !tgAtivo()) return;
  if (tipo == SAI_LIGACAO && !ligacaoAtiva()) return;
  MsgSaida m; m.tipo = tipo; strlcpy(m.texto, txt, sizeof(m.texto));
  xQueueSend(filaSaida, &m, 0);
}
static void alertar(uint8_t canal, const char *msg, bool ligar) {
  uint32_t s = millis() / 1000UL;
  if (ultMsg[canal] == 0 || s - ultMsg[canal] >= COOLDOWN_MSG_S) { enfileirar(SAI_MSG, msg); ultMsg[canal] = s ? s : 1; }
  if (ligar && (ultLig[canal] == 0 || s - ultLig[canal] >= COOLDOWN_LIG_S)) { enfileirar(SAI_LIGACAO, msg); ultLig[canal] = s ? s : 1; }
}
static void textoMetricas(char *out, size_t n, const Metricas &m, const char *titulo) {
  float pctAcima = m.t_total_s > 0 ? 100.0 * m.t_itu_acima_s / m.t_total_s : 0;
  snprintf(out, n,
           "%s\nModo: %s | duracao: %.0f min\nITU medio %.1f (min %.1f / max %.1f)\n"
           "Tempo com ITU >= %.0f: %.0f %%\nCarga termica acima do limiar: %.1f ITU.min\n"
           "Ventilador ligado: %.1f min (plena carga eq.: %.1f min)\n"
           "Energia (estimada/calibrada): %.2f Wh | partidas: %lu | trocas: %lu\n"
           "IG maximo: %.2f (indice relativo, nao e ppm)",
           titulo, NOME_MODO[modo], m.t_total_s / 60.0, m.n_itu ? m.soma_itu / m.n_itu : NAN,
           m.n_itu ? m.itu_min : NAN, m.n_itu ? m.itu_max : NAN, ITU_LIMIAR[0], pctAcima, m.carga_itu_min,
           m.t_ligado_s / 60.0, m.t_eq_s / 60.0, m.energia_wh, (unsigned long)m.n_partidas, (unsigned long)m.n_trocas, m.ig_max);
}
static void textoEstrategias(char *out, size_t n, const Metricas *m) {
  double tot = m[0].t_total_s > 0 ? m[0].t_total_s : 1;
  snprintf(out, n,
           "Comparacao das estrategias (mesmos dados):\nE1 continua: %.1f min eq. (%.0f %%)\n"
           "E2 liga-desliga: %.1f min eq. (%.0f %%), trocas %lu\nE3 adaptativa: %.1f min eq. (%.0f %%), trocas %lu\n"
           "Reducao estimada E3 x E1: %.0f %%",
           m[0].t_eq_s / 60.0, 100.0 * m[0].t_eq_s / tot, m[1].t_eq_s / 60.0, 100.0 * m[1].t_eq_s / tot,
           (unsigned long)m[1].n_trocas, m[2].t_eq_s / 60.0, 100.0 * m[2].t_eq_s / tot, (unsigned long)m[2].n_trocas,
           m[0].t_eq_s > 0 ? 100.0 * (m[0].t_eq_s - m[2].t_eq_s) / m[0].t_eq_s : 0.0);
}

// ============================ SIMULAÇÃO DE EMERGÊNCIA ======================
static void iniciarSimulacao(const char *origem) {
  simAte = millis() + T_SIM_MS; if (!simAte) simAte = 1;
  bipsAgendar(6);
  char m[320];
  snprintf(m, sizeof(m), "[SIMULACAO] Emergencia no BoviSense (acionada por %s): ITU critico e alerta de gases "
           "simulados por %lu s. Ventilacao forcada em 100%%. Dados reais nao foram alterados.", origem, T_SIM_MS / 1000UL);
  enfileirar(SAI_MSG, m);
  if (ultLigSim == 0 || millis() - ultLigSim > INTERVALO_LIG_SIM_MS) {
    enfileirar(SAI_LIGACAO, "Atencao. Emergencia simulada no BoviSense. Temperatura critica e gases detectados. Ventilacao em cem por cento.");
    ultLigSim = millis() ? millis() : 1;
  }
  Serial.printf("# SIMULACAO iniciada por %s\n", origem);
}
static void pararSimulacao() { if (simAte) { simAte = 0; } }

// ============================ AMOSTRAGEM E CONTROLE ========================
static void iniciarEstado(Estado e) { estado = e; tInicioEstado = millis(); }
static void registrar(uint32_t t) {
  Registro &r = regs[regTopo];
  r.t = t;
  r.T10 = isnan(Tf) ? INT16_MIN : (int16_t)lroundf(Tf * 10);
  r.U10 = isnan(Uf) ? INT16_MIN : (int16_t)lroundf(Uf * 10);
  r.ITU10 = isnan(itu) ? INT16_MIN : (int16_t)lroundf(itu * 10);
  r.IG100 = isnan(ig) ? 0xFFFF : (uint16_t)constrain(lroundf(ig * 100), 0, 65000);
  r.mv = (uint16_t)mqmV; r.nivel = nivel; r.duty = dutyAlvo; r.modo = modo; r.flags = flags;
  regTopo = (regTopo + 1) % N_REG; if (regQtd < N_REG) regQtd++;
}
static void imprimirCabecalhoCSV() {
  Serial.println(F("t,modo,estado,T_bruta_C,UR_bruta_pct,T_filt_C,UR_filt_pct,ITU,mq2_mV,IG,estagio_ITU,estagio_gas,nivel,duty_pct,flags"));
}
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
void loop() {
  uint32_t agora = millis();
  if (agora - ultimaAmostra >= T_AMOSTRA_MS || ultimaAmostra == 0) amostrar();
  Comando c;
  while (xQueueReceive(filaCmd, &c, 0) == pdTRUE) {
    if (c.tipo == CMD_MODO) definirModo(c.arg);
    else if (c.tipo == CMD_NOVO_ENSAIO) novoEnsaio();
    else if (c.tipo == CMD_SIMULAR) iniciarSimulacao("Telegram");
    else if (c.tipo == CMD_PARAR_SIM) pararSimulacao();
    else if (c.tipo == CMD_RECAL_GAS && estado == EST_OPER) iniciarRecalGas();
  }
  servicoVentilador(); servicoBotao(); servicoSerial(); bipServico();
  servidor.handleClient();
  delay(2);
}

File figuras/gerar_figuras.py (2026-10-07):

#!/usr/bin/env python3
# Figuras do BoviSense (sem OLED): esquema geral e detalhe do estágio de potência.
import matplotlib
matplotlib.use("Agg")
import matplotlib.pyplot as plt
from matplotlib.patches import FancyBboxPatch, Rectangle, Circle, Polygon, Wedge

AZUL   = "#28445f"
LARANJA= "#e8812a"
VERDE  = "#2f7d4f"
ROXO   = "#7b5ea7"
VERM   = "#c0392b"
PRETO  = "#1b1f1d"
CINZA  = "#9aa29d"
FUNDO  = "#ffffff"

def caixa(ax, x, y, w, h, texto, cor="#f4f6f4", borda=PRETO, fs=12, peso="normal", lw=1.6):
    ax.add_patch(FancyBboxPatch((x, y), w, h, boxstyle="round,pad=0.012,rounding_size=0.03",
                                fc=cor, ec=borda, lw=lw, zorder=3))
    ax.text(x + w/2, y + h/2, texto, ha="center", va="center", fontsize=fs,
            fontweight=peso, color=PRETO, zorder=4, linespacing=1.45)

def fio(ax, pts, cor, lw=3.0, z=2):
    ax.plot([p[0] for p in pts], [p[1] for p in pts], color=cor, lw=lw,
            solid_capstyle="round", solid_joinstyle="round", zorder=z)

def rotulo(ax, x, y, t, cor, fs=11, ha="center", va="center"):
    ax.text(x, y, t, ha=ha, va=va, fontsize=fs, color=cor, fontweight="bold", zorder=6,
            bbox=dict(fc=FUNDO, ec="none", pad=1.2))

def terminal(ax, x, y, t, cor):
    ax.add_patch(FancyBboxPatch((x, y-0.11), 0.42, 0.22, boxstyle="round,pad=0.01,rounding_size=0.04",
                                fc=cor, ec="none", zorder=5))
    ax.text(x+0.21, y, t, ha="center", va="center", fontsize=10.5, color="#fff",
            fontweight="bold", zorder=6)

# =====================================================================
# FIGURA 2 — esquema geral de ligação (sem tela)
# =====================================================================
fig, ax = plt.subplots(figsize=(15.2, 10.4))
ax.set_xlim(0, 15.2); ax.set_ylim(0, 10.4); ax.axis("off")
fig.patch.set_facecolor(FUNDO)

ax.text(7.6, 10.05, "Placa vista de cima, antena para cima e USB para baixo.",
        ha="center", fontsize=13.5, fontweight="bold", color=PRETO)
ax.text(7.6, 9.72, 'Na serigrafia, o número depois do "D" é o número do GPIO: D4 é o GPIO 4.',
        ha="center", fontsize=11.5, color="#555c57")

# ---- placa ESP32 ----
BX, BY, BW, BH = 6.05, 1.30, 3.10, 8.00
ax.add_patch(FancyBboxPatch((BX, BY), BW, BH, boxstyle="round,pad=0.02,rounding_size=0.06",
                            fc=AZUL, ec="#16293a", lw=2, zorder=3))
ax.add_patch(Rectangle((BX+1.00, BY+BH-0.62), 1.10, 0.42, fc="#b9c0bb", ec="#6f7a73", lw=1, zorder=4))
ax.text(BX+1.55, BY+BH-0.41, "antena", ha="center", va="center", fontsize=9.5, color="#2a2f2c", zorder=5)
ax.add_patch(Rectangle((BX+1.18, BY-0.30), 0.74, 0.30, fc="#b9c0bb", ec="#6f7a73", lw=1, zorder=4))
ax.text(BX+1.55, BY-0.52, "micro-USB → power bank", ha="center", fontsize=10.5, color=PRETO)
ax.text(BX+BW/2, BY+BH-1.55, "ESP32\nDevKit\n30 pinos", ha="center", va="center",
        fontsize=15, fontweight="bold", color="#fff", zorder=5, linespacing=1.35)

ESQ = ["EN","VP","VN","D34","D35","D32","D33","D25","D26","D27","D14","D12","D13","GND","VIN"]
DIR = ["D23","D22","TX0","RX0","D21","D19","D18","D5","TX2","RX2","D4","D2","D15","GND","3V3"]
USA = {"D34","D25","D26","D4","GND","3V3"}
PY = {}
p0, dp = BY + BH - 0.95, 0.483
for i, n in enumerate(ESQ):
    y = p0 - i*dp; ativo = n in USA
    ax.add_patch(Circle((BX+0.20, y), 0.085, fc="#f0d57a" if ativo else "#aab2ad",
                        ec="#6f7a73", lw=.8, zorder=5))
    ax.text(BX+0.40, y, n, ha="left", va="center", fontsize=11 if ativo else 10,
            color="#fff" if ativo else "#b6c0b9", fontweight="bold" if ativo else "normal", zorder=5)
    PY[("E", n)] = y
for i, n in enumerate(DIR):
    y = p0 - i*dp; ativo = n in USA
    ax.add_patch(Circle((BX+BW-0.20, y), 0.085, fc="#f0d57a" if ativo else "#aab2ad",
                        ec="#6f7a73", lw=.8, zorder=5))
    ax.text(BX+BW-0.40, y, n, ha="right", va="center", fontsize=11 if ativo else 10,
            color="#fff" if ativo else "#b6c0b9", fontweight="bold" if ativo else "normal", zorder=5)
    PY[("D", n)] = y

# ---- MQ-2 ----
caixa(ax, 0.75, 7.75, 3.30, 1.05, "MQ-2\nVCC   GND   DO   AO", cor="#fdf0e2", fs=12.5)
ax.text(2.40, 7.52, "DO não é usado: deixe solto", ha="center", fontsize=10, style="italic", color="#555c57")
terminal(ax, 0.12, 8.56, "3V3", VERM); ax.text(0.33, 8.84, "VCC", ha="center", fontsize=9.5, color="#555c57")
terminal(ax, 0.12, 8.02, "GND", "#5b6560"); ax.text(0.33, 7.74, "GND", ha="center", fontsize=9.5, color="#555c57")
fio(ax, [(0.54, 8.56), (0.75, 8.56)], VERM, lw=2.2)
fio(ax, [(0.54, 8.02), (0.75, 8.02)], "#5b6560", lw=2.2)
yA = PY[("E","D34")]
fio(ax, [(4.05,8.00),(5.20,8.00),(5.20,yA),(BX+0.20,yA)], LARANJA)
rotulo(ax, 5.20, (8.00+yA)/2, "AO", LARANJA)

# ---- buzzer ----
yB = PY[("E","D25")]
caixa(ax, 0.75, 5.55, 3.30, 0.95, "Buzzer piezo\n+            −", cor="#f2ecfa", fs=12.5)
terminal(ax, 0.12, 5.78, "GND", "#5b6560")
fio(ax, [(0.54, 5.78), (0.75, 5.78)], "#5b6560", lw=2.2)
fio(ax, [(4.05,6.26),(5.55,6.26),(5.55,yB),(BX+0.20,yB)], ROXO)
rotulo(ax, 5.55, (6.26+yB)/2, "+", ROXO, fs=13)

# ---- estágio de potência (bloco; detalhe na figura seguinte) ----
yF = PY[("E","D26")]
caixa(ax, 0.75, 2.35, 4.35, 2.45,
      "ESTÁGIO DE POTÊNCIA\n\nTIP122  ·  resistores de 1 kΩ e 10 kΩ\ndiodo 1N4007  ·  bateria 9 V  ·  cooler\n\nligações detalhadas na Figura 3",
      cor="#eaf3ed", borda=VERDE, fs=12, lw=2.4)
fio(ax, [(5.10,4.10),(5.72,4.10),(5.72,yF),(BX+0.20,yF)], VERDE)
rotulo(ax, 5.35, 4.10, "PWM", VERDE)
ax.text(2.92, 2.08, "fica na placa perfurada, fora da maquete", ha="center", fontsize=10,
        style="italic", color="#555c57")
terminal(ax, 0.12, 2.95, "GND", "#5b6560")
fio(ax, [(0.54, 2.95), (0.75, 2.95)], "#5b6560", lw=2.2)

# ---- DHT11 ----
yD = PY[("D","D4")]
caixa(ax, 11.15, yD-0.52, 2.80, 1.05, "DHT11\n+            −            OUT", cor="#e6f0f8", fs=12.5)
fio(ax, [(BX+BW-0.20,yD),(11.15,yD)], VERDE)
rotulo(ax, (BX+BW+11.15)/2 - 0.10, yD+0.21, "OUT", VERDE)
terminal(ax, 14.12, yD+0.30, "3V3", VERM); ax.text(14.33, yD+0.58, "+", ha="center", fontsize=12.5, color="#555c57")
terminal(ax, 14.12, yD-0.26, "GND", "#5b6560"); ax.text(14.33, yD-0.54, "−", ha="center", fontsize=12.5, color="#555c57")
fio(ax, [(13.95, yD+0.30), (14.12, yD+0.30)], VERM, lw=2.2)
fio(ax, [(13.95, yD-0.26), (14.12, yD-0.26)], "#5b6560", lw=2.2)

# ---- trilhos ----
terminal(ax, BX+BW+0.25, PY[("D","GND")], "GND", "#5b6560")
fio(ax, [(BX+BW-0.20,PY[("D","GND")]),(BX+BW+0.25,PY[("D","GND")])], "#5b6560", lw=2.4)
terminal(ax, BX+BW+0.25, PY[("D","3V3")], "3V3", VERM)
fio(ax, [(BX+BW-0.20,PY[("D","3V3")]),(BX+BW+0.25,PY[("D","3V3")])], VERM, lw=2.4)

ax.text(11.15, 8.40, "SEM TELA", fontsize=13, fontweight="bold", color=VERDE)
ax.text(11.15, 8.05,
        "A leitura local é o painel web:\nconecte o celular à rede BoviSense\ne abra 192.168.4.1\n\n"
        "O diagnóstico de inicialização sai\npelo Monitor Serial e por bipes.",
        fontsize=11, color="#30403a", va="top", linespacing=1.6)
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

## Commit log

2026-09-19 Atualização da modelagem 3D
    [Case-do-prototipo.f3d, Prototipo-3Dprinter.3mf, case.3mf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]
2026-09-19 Atualização modelagem 3D
    [DHT11.3mf, MQ-2.3mf]
2026-09-19 Anexo de referências
2026-10-28 Update references for ESP32 case and add new link
2026-10-28 Revise README for clarity on prototype and results
    Updated README to clarify prototype details and limitations.
